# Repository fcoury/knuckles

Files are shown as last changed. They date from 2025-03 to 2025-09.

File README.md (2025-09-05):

# Knuckles

An open-source, column-staggered ergonomic keyboard. This repo contains everything to generate the PCBs, plates, renders/gerbers, and a simple printable bottom case tray.

Knuckles with Case

It includes two PCB variants defined in `ergogen/config.yaml`:

- `knuckles`: wired variant (TRRS, small display)
- `knuckles_wireless`: wireless-ready variant (power switch, battery connector, e-paper display)

Both variants use reversible footprints and support per-key LEDs (SK6812mini-E) plus a small underglow chain. FR4 front/back plates and a controller overlay are also generated.

**Images**

- Front plate: `images/frontplate-top.png`, `images/frontplate-bottom.png`
- Back plate: `images/backplate-top.png`, `images/backplate-bottom.png`
- Controller overlay: `images/controller_overlay-top.png`, `images/controller_overlay-bottom.png`

## Requirements

- Node.js 18+ (CI uses Node 20)
- Docker (for the KiCad/KiBot/Freerouting pipeline in the shell scripts)
- Git with submodules (footprints are vendored as a submodule)
- Optional: macOS `fswatch` for `watch.sh` live-regeneration

Clone with submodules:

```
git clone --recursive <repo-url>
```

Install JS deps:

```
npm install
```

## Quick Start

There are two ways to build, depending on how much automation you want.

- Ergogen-only (local, fast):
  - `npm run build` → generates PCBs/plates from `ergogen/config.yaml` and the case STL.
  - `npm run debug` → same as build but with Ergogen debug output.
  - `npm run watch:build` / `npm run watch:debug` → rebuild on YAML/JS changes.

- Full pipeline (Docker, KiCad + Freerouting):
  - `./build.sh` →
    - Cleans previous outputs
    - Runs Ergogen (unrouted boards + plates)
    - Runs KiBot to export renders/gerbers for plates and unrouted board
    - Exports DSN, autoroutes with Freerouting, imports SES back into KiCad
    - Runs KiBot again for the autorouted board
    - Outputs live in `pcbs/`, `outlines/`, `ergogen/output/images`, `ergogen/output/gerbers`
  - `./rebuild.sh` → re-export/autoroute existing boards in `pcbs/` without regenerating from Ergogen.
  - `./watch.sh` (macOS) → regenerates PCB on config change and opens the result.

Notes:

- If case STL generation fails, check the path in `package.json` (`cases/knuckles_bottom_tray.jscad`) vs the file in `cases/`.
- Shell scripts expect Docker to be available and will pull/use containers automatically.

## Outputs

- `pcbs/` — KiCad 8 `.kicad_pcb` files for boards and plates.
- `outlines/` — DXF/SVG outlines used by the PCBs and case.
- `cases/` — JSCAD source and generated STL for a bottom tray.
- `ergogen/output/images` — board renders (from KiBot/PCBDraw).
- `ergogen/output/gerbers/<board>` — JLCPCB-ready Gerbers and drills (zipped by KiBot).
- `images/` — reference renders checked into the repo.

## Customizing

Edit `ergogen/config.yaml`:

- Layout: matrix and thumb-fan are under `points.zones.*` (spacing, splay, stagger).
- Switch footprint: set `meta.footprint` and optionally switch `presets` (`mx`, `choc_v1`, `choc_v2`, or the provided low-profile/reversible footprints).
- Electrical nets: column/row nets are assigned per zone; MCU pins are mapped in the `mcu` footprint section.
- LEDs: per‑key and underglow chains can be tweaked (trace widths, via sizes, positions).
- Case: see `cases/` and the outlines under `outlines/_bottom_case*` to adapt walls and cutouts.

After changes, rebuild via Ergogen (`npm run build`) or run the full pipeline (`./build.sh`).

## CI

A GitHub Actions workflow (`.github/workflows/build.yaml`) reproduces the full pipeline in containers:

- Ergogen generation
- KiBot renders + Gerbers (plates and board)
- DSN export → Freerouting autoroute → SES import
- Artifacts: `cases`, `gerbers`, `images`, `outlines`, `pcbs`

## Manufacturing

Use the KiBot-produced ZIP under `ergogen/output/gerbers/<board>` for JLCPCB. The KiBot configs (`kibot/default.kibot.yaml`, `kibot/boards.kibot.yaml`) are tuned for JLCPCB and include common filters for autorouted boards.

## Folder Structure (high level)

- `ergogen/` — main Ergogen project (`config.yaml`, footprints, generated output)
- `pcbs/` — KiCad boards (unrouted and autorouted variants)
- `kibot/` — KiBot configs and helper scripts (DSN export / SES import)
- `freerouting/` — rules, JARs, and logging for autorouting
- `cases/` — JSCAD for the printed bottom tray
- `images/` — reference images of plates
- `build.sh`, `rebuild.sh`, `watch.sh` — automation scripts

## License

MIT © 2024 Felipe Coury (see `LICENSE`).

## Credits

- Ergogen 4 and community for the generation engine.
- Custom footprints from `ergogen/footprints/ceoloide` (submodule) and related authors.
- Freerouting for autorouting; KiBot + PCBDraw for renders/exports.

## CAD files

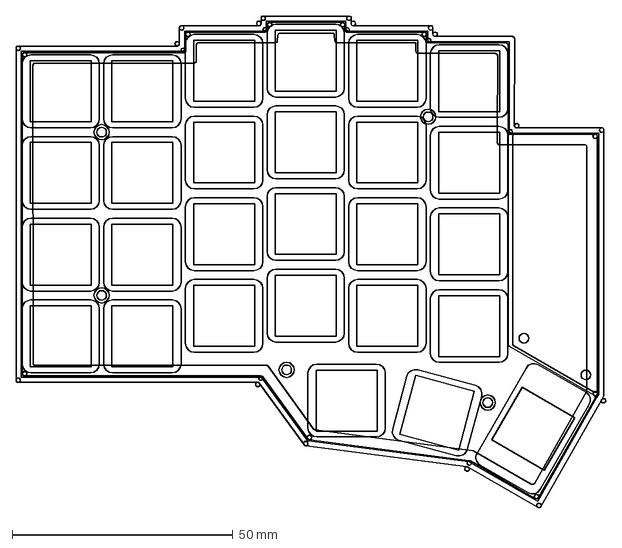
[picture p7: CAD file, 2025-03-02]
ergogen/output/outlines/preview.dxf
133.7 x 111.4 mm

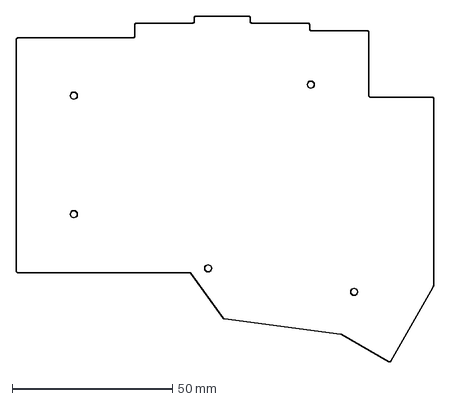
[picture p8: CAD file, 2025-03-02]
ergogen/output/outlines/backplate.dxf
130.3 x 107.9 mm

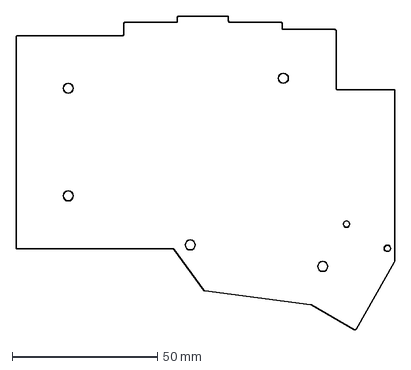
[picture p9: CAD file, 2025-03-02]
outlines/pcb.dxf
130.3 x 107.9 mm

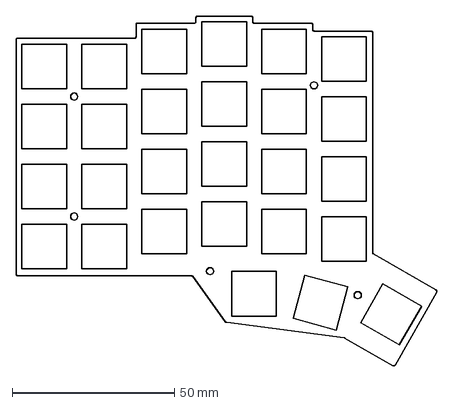
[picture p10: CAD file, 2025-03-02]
ergogen/output/outlines/frontplate.dxf
129.8 x 107.9 mm

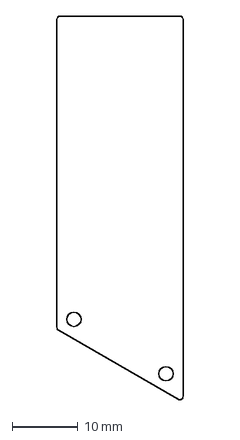
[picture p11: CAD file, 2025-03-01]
ergogen/output/outlines/controller_overlay.dxf
19.2 x 58.5 mm

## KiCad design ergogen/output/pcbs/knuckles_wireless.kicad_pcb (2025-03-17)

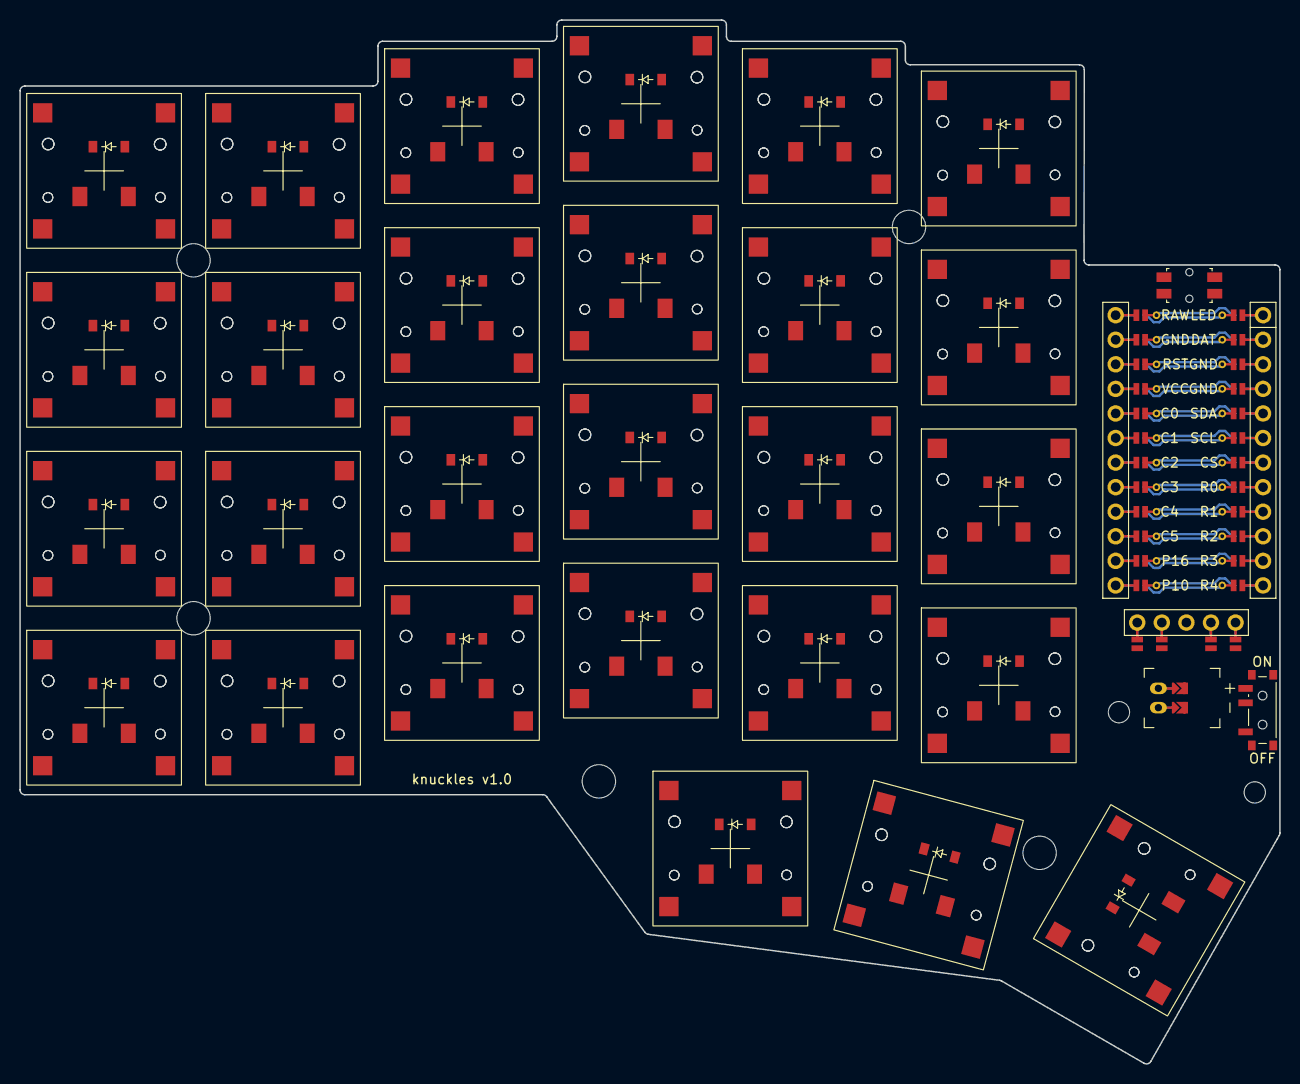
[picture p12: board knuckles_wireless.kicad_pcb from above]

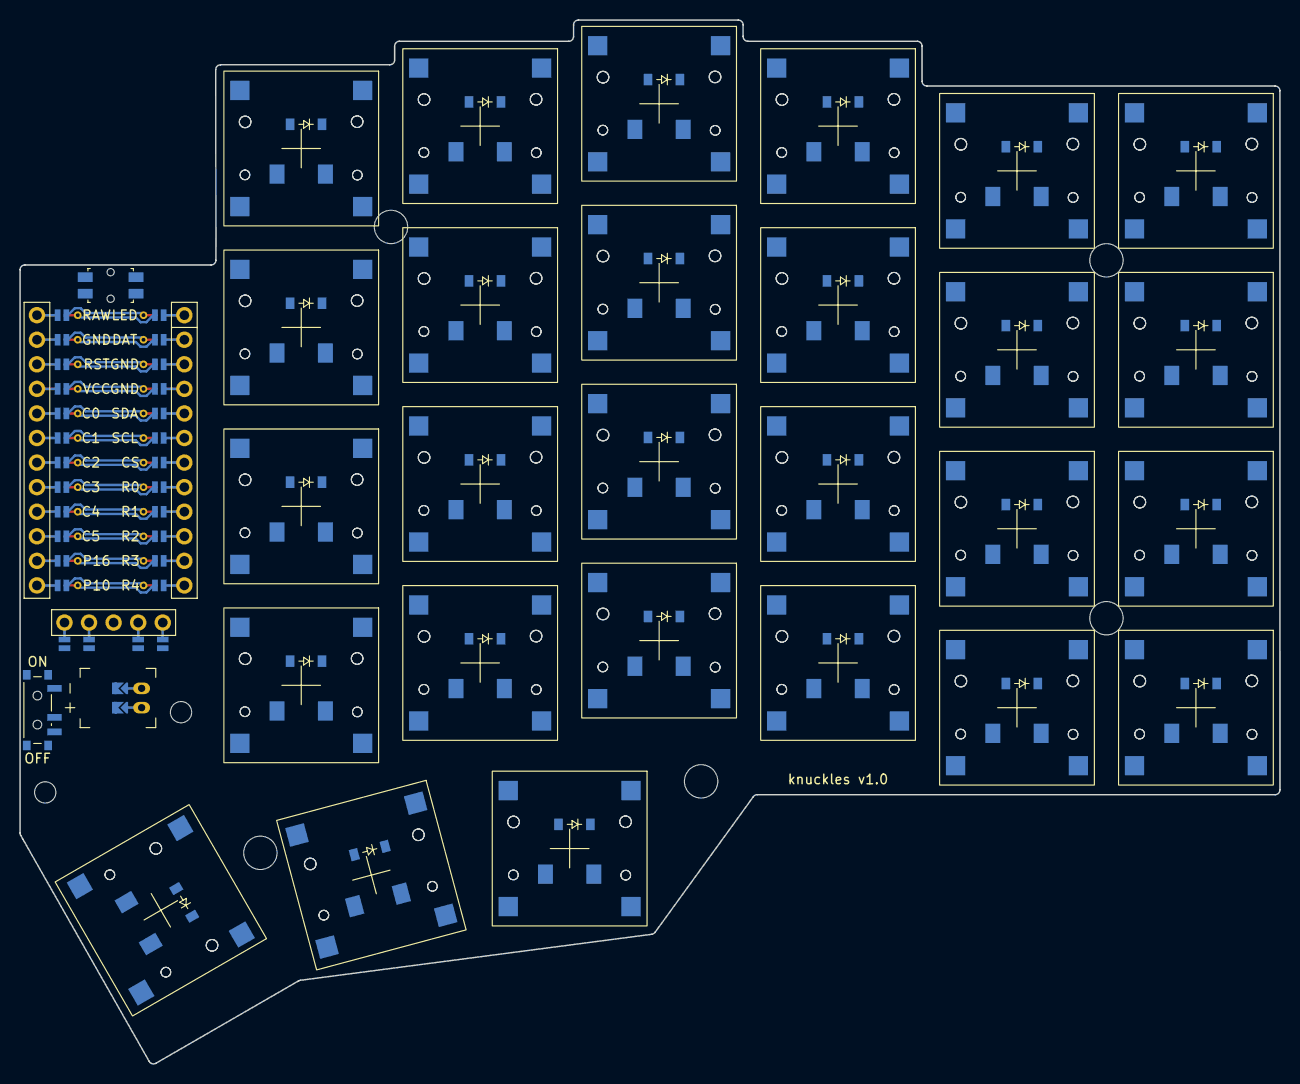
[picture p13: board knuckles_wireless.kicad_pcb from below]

Board: 2 copper layers, 130.3 x 107.9 mm, 120 parts (54 on the bottom side), 79 nets.

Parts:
D1, D2, D3, D4, D5, D6, D7, D8, D9, D10, D11, D12, D13, D14, D15, D16, D17, D18, D19, D20, D21, D22, D23, D24, D25, D26, D27, D28, D29, D30, D31, D32, D33, D34, D35, D36, D37, D38, D39, D40, D41, D42, D43, D44, D45, D46, D47, D48, D49, D50, D51, D52, D53, D54: diode_tht_sod123
DISP1: display_nice_view
JST1: battery_connector_jst_ph_2
MCU1: mcu_nice_nano
MH1, MH2, MH3, MH4, MH5, MH6, MH7: mounting_hole_npth
PWR1: power_switch_smd_side
RST1: reset_switch_smd_side
S1, S2, S3, S4, S5, S6, S7, S8, S9, S10, S11, S12, S13, S14, S15, S16, S17, S18, S19, S20, S21, S22, S23, S24, S25, S26, S27, S28, S29, S30, S31, S32, S33, S34, S35, S36, S37, S38, S39, S40, S41, S42, S43, S44, S45, S46, S47, S48, S49, S50, S51, S52, S53, S54: CPG1316S01D02

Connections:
BAT_P: JST1.1, PWR1.1, PWR1.3
C0: MCU1.120, S1.1, S2.1, S3.1, S4.1, S28.1, S29.1, S30.1, S31.1
C1: MCU1.119, S5.1, S6.1, S7.1, S8.1, S32.1, S33.1, S34.1, S35.1
C2: MCU1.118, S9.1, S10.1, S11.1, S12.1, S36.1, S37.1, S38.1, S39.1
C3: MCU1.117, S13.1, S14.1, S15.1, S16.1, S25.1, S40.1, S41.1, S42.1, S43.1, S52.1
C4: MCU1.116, S17.1, S18.1, S19.1, S20.1, S26.1, S44.1, S45.1, S46.1, S47.1, S53.1
C5: MCU1.115, S21.1, S22.1, S23.1, S24.1, S27.1, S48.1, S49.1, S50.1, S51.1, S54.1
CS: DISP1.10, DISP1.20, MCU1.107
DISP1_1: DISP1.1, DISP1.14, DISP1.27
DISP1_2: DISP1.2, DISP1.15, DISP1.26
DISP1_4: DISP1.4, DISP1.16, DISP1.25
DISP1_5: DISP1.5, DISP1.17, DISP1.24
GND: DISP1.11, DISP1.21, JST1.2, MCU1.103, MCU1.104, MCU1.123, RST1.1, RST1.3
JST1_1: JST1.11, JST1.21, JST1.31
JST1_2: JST1.12, JST1.22, JST1.32
R0: D4.1, D8.1, D12.1, D16.1, D20.1, D24.1, D31.1, D35.1, D39.1, D43.1, D47.1, D51.1, MCU1.108
R1: D3.1, D7.1, D11.1, D15.1, D19.1, D23.1, D30.1, D34.1, D38.1, D42.1, D46.1, D50.1, MCU1.109
R2: D2.1, D6.1, D10.1, D14.1, D18.1, D22.1, D29.1, D33.1, D37.1, D41.1, D45.1, D49.1, MCU1.110
R3: D1.1, D5.1, D9.1, D13.1, D17.1, D21.1, D28.1, D32.1, D36.1, D40.1, D44.1, D48.1, MCU1.111
R4: D25.1, D26.1, D27.1, D52.1, D53.1, D54.1, MCU1.112
RAW: MCU1.124, PWR1.2
RST: MCU1.122, RST1.2, RST1.4
SCL: DISP1.12, DISP1.22, MCU1.106
SDA: DISP1.13, DISP1.23, MCU1.105
VCC: DISP1.3, MCU1.121
far_home_B: D27.2, S27.2
far_home_F: D54.2, S54.2
index_bottom_B: D17.2, S17.2
index_bottom_F: D44.2, S44.2
index_home_B: D18.2, S18.2
index_home_F: D45.2, S45.2
index_numbers_B: D20.2, S20.2
index_numbers_F: D47.2, S47.2
index_top_B: D19.2, S19.2
index_top_F: D46.2, S46.2
inner_bottom_B: D21.2, S21.2
inner_bottom_F: D48.2, S48.2
inner_home_B: D22.2, S22.2
inner_home_F: D49.2, S49.2
inner_numbers_B: D24.2, S24.2
inner_numbers_F: D51.2, S51.2
inner_top_B: D23.2, S23.2
inner_top_F: D50.2, S50.2
mid_home_B: D26.2, S26.2
mid_home_F: D53.2, S53.2
middle_bottom_B: D13.2, S13.2
middle_bottom_F: D40.2, S40.2
middle_home_B: D14.2, S14.2
middle_home_F: D41.2, S41.2
middle_numbers_B: D16.2, S16.2
middle_numbers_F: D43.2, S43.2
middle_top_B: D15.2, S15.2
middle_top_F: D42.2, S42.2
near_home_B: D25.2, S25.2
near_home_F: D52.2, S52.2
outer_bottom_B: D1.2, S1.2
outer_bottom_F: D28.2, S28.2
outer_home_B: D2.2, S2.2
outer_home_F: D29.2, S29.2
outer_numbers_B: D4.2, S4.2
outer_numbers_F: D31.2, S31.2
outer_top_B: D3.2, S3.2
outer_top_F: D30.2, S30.2
pinky_bottom_B: D5.2, S5.2
pinky_bottom_F: D32.2, S32.2
pinky_home_B: D6.2, S6.2
pinky_home_F: D33.2, S33.2
pinky_numbers_B: D8.2, S8.2
pinky_numbers_F: D35.2, S35.2
pinky_top_B: D7.2, S7.2
pinky_top_F: D34.2, S34.2
ring_bottom_B: D9.2, S9.2
ring_bottom_F: D36.2, S36.2
ring_home_B: D10.2, S10.2
ring_home_F: D37.2, S37.2
ring_numbers_B: D12.2, S12.2
ring_numbers_F: D39.2, S39.2
ring_top_B: D11.2, S11.2
ring_top_F: D38.2, S38.2

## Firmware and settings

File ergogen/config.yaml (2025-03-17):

meta:
  engine: 4.1.0
  name: knuckles
  version: 0.2
  ref: &kb_ref "knuckles v0.1"
  author: ceoloide
  url: &kb_url https://github.com/ceoloide/knuckles
  footprint: &switch_footprint "pg1316s_reversible"
  # footprint: &switch_footprint "ceoloide/switch_mx"
  # footprint: &switch_footprint "ceoloide/switch_choc_v1_v2"
  switch:
    $extends: presets.pg1316s
    # $extends: presets.mx
    # $extends: presets.choc_v1
    # $extends: presets.choc_v2

presets:
  # These presets provide different layout options
  # Select a preset in the `units` section below
  # Note: The appropriate switch footprint will still need to be set in the `pcb` section
  pg1316s:
    # Key and keycap measures
    kx: 13.5 # spacing between key centers (X-axis)
    ky: 13 # spacing between key centers (Y-axis)
    ks: 18.5 # horizontal space between columns (default: 19)
    kp: 18.5 # vertical padding between keys (deafult: 19)
    kpx: ks * 0.5 # x padding for the outline
    kpy: kp * 0.5 # y padding for the outline
    kcow: 13.8 # key cutout hole width (cherry, choc v2: 14, choc v1: 13.8)
    kcoh: 13.8 # key cutout hole height (cherry, choc v2: 14, choc v1: 13.8)
    keycw: 17.5 # keycap width (cherry: 18, choc: 17.5)
    keych: 16.5 # keycap height (cherry: 18, choc: 16.5)
    led_pos_x: 0 # Led X position relative to the switch center
    led_pos_y: 4.7 # Led Y position relative to the switch center
    led_rotation: 0 # Led rotation
    vertical_underglow_shift: -kp + 7.8 # How much to shift underglow leds tied to keys
    vertical_diode_shift: 2.5 # How much to shift to avoid overlap
    horizontal_diode_shift: -0.5
    diode_rotation: -90 # Diode rotation
    switch_rotation: 0
  mx:
    # Key and keycap measures
    kx: u # spacing between key centers (X-axis)
    ky: u # spacing between key centers (Y-axis)
    ks: 19 # horizontal space between columns (default: 19)
    kp: 19 # vertical padding between keys (deafult: 19)
    kcow: 14 # key cutout hole width (cherry: 14, choc: 13.8)
    kcoh: 14 # key cutout hole height (cherry: 14, choc: 13.8)
    keycw: 18 # keycap width (cherry: 18, choc: 17.5)
    keych: 18 # keycap height (cherry: 18, choc: 16.5)
    led_pos_x: 0 # Led X position relative to the switch center
    led_pos_y: -4.75 # Led Y position relative to the switch center
    led_rotation: 180 # Led rotation
    vertical_underglow_shift: -0.5 kp # How much to shift underglow leds tied to keys
    vertical_diode_shift: 1.325 # How much to shift to avoid overlap
    horizontal_diode_shift: 7.4
    diode_rotation: 0 # Diode rotation
    switch_rotation: 0 # Hotswap north, led south
  choc_v1:
    # Key and keycap measures
    kx: cx # spacing between key centers (X-axis)
    ky: cy # spacing between key centers (Y-axis)
    ks: 18.5 # horizontal space between columns (default: 19)
    kp: 17.5 # vertical padding between keys (deafult: 19)
    kcow: 13.8 # key cutout hole width (cherry, choc v2: 14, choc v1: 13.8)
    kcoh: 13.8 # key cutout hole height (cherry, choc v2: 14, choc v1: 13.8)
    keycw: 17.5 # keycap width (cherry: 18, choc: 17.5)
    keych: 16.5 # keycap height (cherry: 18, choc: 16.5)
    led_pos_x: 0 # Led X position relative to the switch center
    led_pos_y: 4.7 # Led Y position relative to the switch center
    led_rotation: 0 # Led rotation
    vertical_underglow_shift: -kp + 7.8 # How much to shift underglow leds tied to keys
    vertical_diode_shift: 1.5 # How much to shift to avoid overlap
    horizontal_diode_shift: -0.5 kcow - 0.85
    diode_rotation: -180 # Diode rotation
    switch_rotation: 180 # Hotswap south, led north
  choc_v2:
    # Key and keycap measures
    $extends: presets.choc_v1
    kx: u # spacing between key centers (X-axis)
    ky: u # spacing between key centers (Y-axis)
    ks: 19 # horizontal space between columns (default: 19)
    kp: 19 # vertical padding between keys (deafult: 19)
    keycw: 18 # keycap width (cherry: 18, choc: 17.5)
    keych: 18 # keycap height (cherry: 18, choc: 16.5)

units:
  # The following statements will make the content of the preset
  # available in the units context
  $extends: meta.switch

  hand_rotation: 0

  # Physical measures
  screw_radius: 1.1 # M2 screws
  screw_diameter: screw_radius * 2
  screw_head_radius: 2.05
  screw_head_diameter: screw_head_radius * 2
  # spacer_radius: 2.15 # M2 standoffs
  spacer_radius: 1.725 # M2 standoffs
  spacer_diameter: spacer_radius * 2
  fillet_radius: 0.5
  pwr_trace_width: 0.25
  gnd_trace_width: 0.25
  signal_trace_width: 0.15
  via_size: 0.56 # JLCPCB min 0.56 | KiCad default 0.8
  via_drill: 0.3 # JLCPCB min 0.3 | KiCad default 0.4

  # Case variables
  case_wall_thickness: 1.2
  pcb_to_case_wall_tolerance: 0.25
  bottom_plate_thickness: 1.0
  top_plate_thickness: 1.6
  internal_distance_between_plates: 4

  # Thumb splay
  splay_thumb_middle: 15
  splay_thumb_far: 15
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

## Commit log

2025-03-01 chore: initial commit
    [backplate.dxf, backplate.kicad_pcb, controller_overlay.dxf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]
2025-03-02 feat: reversible pg1316s switch footprint
    [backplate.dxf, backplate.kicad_pcb, controller_overlay.kicad_pcb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]
2025-03-02 fix: pg1316s pads cannot be tht on reversible pcb
    [zeph.kicad_pcb, zeph_wireless.kicad_pcb]
2025-03-02 feat: board text
    [zeph.kicad_pcb, zeph_wireless.kicad_pcb]
2025-03-02 fix: correct board name
2025-03-02 chore: removed old corney_island files
    [corney_island.kicad_pcb, corney_island_wireless.kicad_pcb]
2025-03-02 feat: build script and its artifacts
    [backplate-B_Cu.gbl, backplate-B_Mask.gbs, backplate-B_Silkscreen.gbo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]
2025-03-17 feat: renamed zeph board to knuckles (#1)
    * feat: renamed zeph
    * fix: github action board name
    * chore: more renaming
    [backplate-B_Cu.gbl, backplate-B_Mask.gbs, backplate-B_Silkscreen.gbo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]
2026-07-13 fix(pcb): persist kicad project settings
    Store the wireless KiCad design rules outside generated output and sync
    them after each Ergogen run. This preserves the 0.25 mm JLCPCB edge
    clearance.
    Also correct the wireless PCB filename and embedded labels so tooling
    consistently uses `knuckles`.
2026-07-14 fix(pcb): increase key spacing and correct power switch
    Set the PG1316S key pitch to 19.5 mm in both axes and regenerate the tracked PCB and outline artifacts.
    Keep the power switch mapping consistent with the intended on/off orientation while preserving the original board outline.
2026-07-14 feat(core): add pg1316s 3d model
    Vendor the Kailh switch assembly and reference it through a
    portable project-relative path.
    Render only the populated PCB face so KiCad previews match the
    intended physical assembly.
2026-10-17 feat: prepare wireless board for TPS43 and validate autorouting
2026-10-18 feat: add thin cases for legacy boards and TPS43 support
2026-10-18 feat: add Knuckles logo and reversible PCB silkscreen
2026-10-18 feat: make PCB spacing selectable during builds
2026-10-18 feat: default to compact 18.5 mm layout and refresh generated boards
2026-10-18 Integrate controller layouts and validate power and firmware design
2026-10-18 Archive ordered wireless PCB and manufacturing files
2026-10-18 Show Knuckles artwork and PCB preview in README
2026-10-18 Rewrite README for first-time readers
    The README had grown one change at a time and read like a changelog.
    Lead with why the board exists and its specs, drop the unsupported wired
    variant and LED claims, condense the spacing caveats into a gotchas list,
    merge the overlapping outputs/folder sections, and document the
    manufacturing archive.
    Also remove cases/knucles_bottom_tray.jscad, stale Ergogen output left
    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
2026-10-18 Sync integrated mouse buttons and record integration validation
2026-11-13 docs: add wireless keyboard bill of materials
